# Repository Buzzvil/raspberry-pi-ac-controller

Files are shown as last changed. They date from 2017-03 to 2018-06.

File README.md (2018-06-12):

# 들어가기에 앞서
- 본 프로젝트는 외부에 공개되어 있으므로 민감한 정보가 프로젝트에 추가되지 않도록 주의해주세요.
- 개발 환경은 OSX 기준으로 되어있습니다.

# 파이콘 2017 발표자료
- [Slideshare](https://www.slideshare.net/JueunSeo1/a-to-z-78795675)
- PDF 원본

# 프로젝트 목표
- 사무실 내 3대의 에어컨을 음성 제어를 이용해 편하게 켜고 끄는게 목표입니다.
- 에어컨 2대는 같은 브랜드, 다른 한대는 다른 브랜드라서 에어컨을 켤 때 리모콘을 두 개 찾아야 하는 불편함이 있는데 이를 해결하여 에어컨 리모컨을 찾는데 들어가는 시간을 절약하여 업무 효율성을 높이자.

# TODO
- [X] [회로도 그리기](#회로도)
- [X] 빵판에 회로 만들기
- [X] 리모컨에서 나오는 ir신호 캡쳐
- [ ] 캡쳐된 ir신호 발신기 conf 파일 셋업
- [ ] irsend 이용해 에어컨 제어하기
- [ ] 서버 셋업
- [X] ngrok을 활용한 고정 public ip 할당
- [X] 도커 배포 환경 구축
- [ ] 모든 배포 환경 자동화
- [X] 만능 기판에 ir발신기 회로 구성
- [X] 아마존 에코 연동
- [ ] 슬랙으로 에어컨 켜고/끄기
- [X] 3일 이상 켜놔도 문제없이 동작하는지 확인

# 회로도
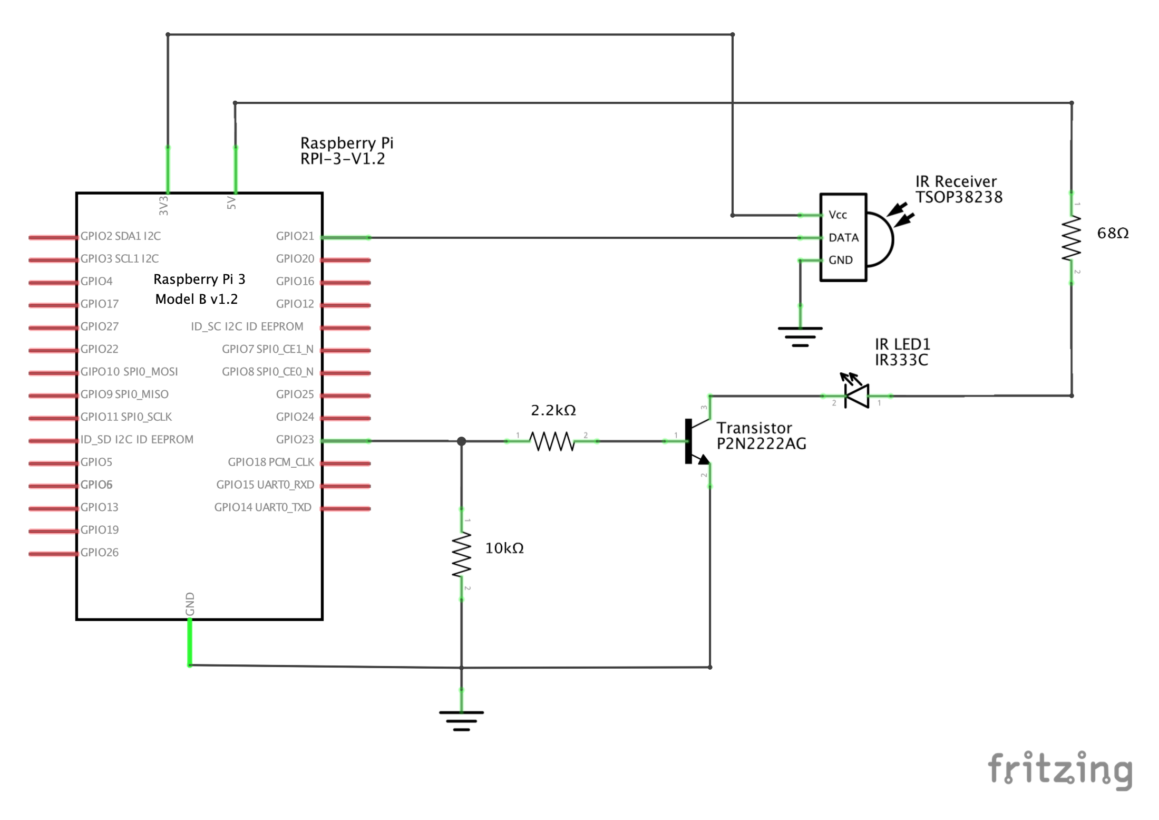
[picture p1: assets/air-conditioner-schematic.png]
schematic

Download [fritzing file(.fzz)](air-conditioner.fzz)

# 어플리케이션 구조도
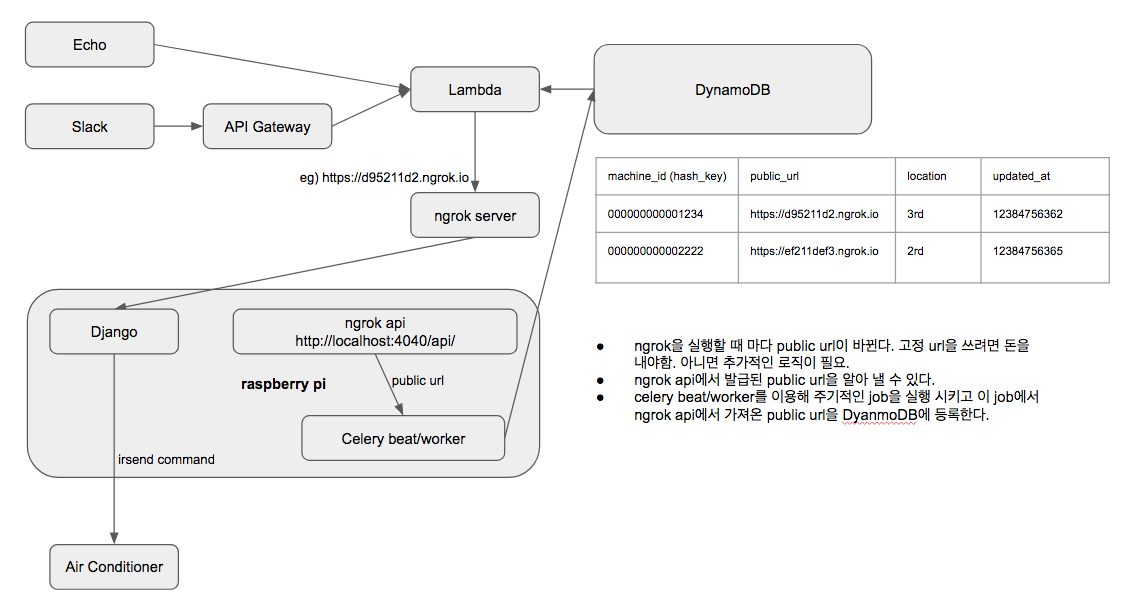
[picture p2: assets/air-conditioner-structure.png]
structure

[원본](https://docs.google.com/presentation/d/10ZRbJJHFH7znxYNwCARpbbcZcShggCh8eihLedmicmc/edit#slide=id.p)

# 회로 구성
## 준비물
- [라즈베리파이 3](http://www.eleparts.co.kr/EPXGNNFF)
- USB 아답터 2.5A 이상
- MLC SD card 16기가 -> Sandisk micro sd extreme 16GB 구매
- [빵판 or 라즈베리파이 입출력키트](http://www.eleparts.co.kr/EPXDTWPM) - 귀찮으면 입출력키트 지르자
- lirc에서 설정하는 gpio_in_pin 등의 번호는 pin 번호가 아닌 gpio 번호를 사용해야한다. 

# 개발 환경

## 라즈비안 설치 without monitor & keyboard
- [SD Card Formatter](https://www.sdcard.org/downloads/formatter_4/) 받아서 SD카드 포맷
- https://www.raspberrypi.org/downloads/raspbian/ 에서 lite version 이미지 받고 압축 풀어서 .img 파일을 실행시키면 boot volume이 마운트된다
  - http://downloads.raspberrypi.org/raspbian_lite/images/raspbian_lite-2017-04-10/2017-04-10-raspbian-jessie-lite.zip 사용 필요
  - 최신 os인 stretch에서는 samsung-ac의 irsend 동작이 됐다 안됐다 불안정하고 lg-ac에서는 간헐적으로 "irsend: timeout" 발생하는 문제가 있어 해결 될 때 까지 jessie사용 필요. 2018년 6월 12일 현재까지 문제 해결되어 있지 않음.
  - https://www.raspberrypi.org/forums/viewtopic.php?t=200865
- 기본으로 ssh가 꺼져 있기 때문에 켜기 위해서 아래처럼 파일을 생성해준다
```bash
sudo touch /Volumes/boot/ssh
```

- 아래 파일을 열어서 내용추가
```bash
sudo vi /Volumes/boot/wpa_supplicant.conf
```
```
ctrl_interface=DIR=/var/run/wpa_supplicant GROUP=netdev
update_config=1
country=US
network={
    ssid="ESSID"
    psk="Your_wifi_password"
    priority=1
}
network={
    ssid="ESSID"
    psk="Your_wifi_password"
    priority=2
    scan_ssid=1
}
```
- scan_ssid -> hidden ssid인 경우 필요
- 실제로 SD카드에 올라가고 나면 /etc/wpa_supplicant/wpa_supplicant.conf 위치에서 같은 파일 찾을 수 있다 
- [pi-baker](https://www.tweaking4all.com/software/macosx-software/macosx-apple-pi-baker/) 받아서 Restore Back으로 img파일 굽기
- network에서 라즈베리파이 찾기
```
which apr || brew install arp-scan
arp -a | grep b8:27:eb | grep -Eo '[0-9]{1,3}\.[0-9]{1,3}\.[0-9]{1,3}\.[0-9]{1,3}'

or
which nmap || brew install nmap
nmap -sn 192.168.1.0/24
```
- ssh pi@xxx.xxx.xxx.xx with password raspberry

- sudo raspi-config 실행해서 ssh 비번 바꾸기
- mkdir ~/.ssh -> vi ~/.ssh/authorized_keys 실행해서 public key 넣어놓기
- ansible로 필요한것들 설치
```bash
cd deploy/rpi/ansible
ansible-playbook -i pi@192.168.0.113, setup_rpi.yml
```

## Docker
- https://www.docker.com/docker-mac

## sshfs 설정
- https://www.raspberrypi.org/documentation/remote-access/ssh/sshfs.md
- 맥에서 아래 명령 수행
```
brew install Caskroom/cask/osxfuse
brew install sshfs
mkdir pi
sshfs pi@192.168.0.109: pi
```

## LIRC 이용한 적외선 신호 발신기 등록 및 신호 송신

- LIRC(Linux Infrared Remote Control) : http://www.lirc.org/html/configuration-guide.html
- 라이브러리 및 환경 설정은 다 되어있다는 가정

1. IR receiver 와 lirc 간 연계 테스트 : 셋업해 둔 IR receiver 가 lirc 로 정상적으로 IR 신호를 전달하고 있는지 확인용.

```bash
sudo /etc/init.d/lirc stop // lirc deamon 중단
mode2 -d /dev/lirc0
```

실행 후 IR 송신기의 버튼을 눌렀을 때 터미널에 `space, pulse` 등의 문자가 출력되면 정상.

2. irrecord 이용해 송신기의 환경 설정 파일 생성
- lirc 가 중지된 상태여야 함
```bash
irrecord -d /dev/lirc0 --disable-namespace -f ~/lircd.conf
```
- `--disable-namespace` : 각 키에 할당할 수 있는 lable의 리스트가 원래 정해져 있는데, 사용할 label을 직접 정의해서 사용하려고 하는 경우 추가. 원래 정의할 수 있는 label 리스트는 `irrecord --list-namespace` 로 조회 가능.

3. samsung ac 인식
- irrecord 대신에 mode2 사용해야함
```
sudo mode2 -m -d /dev/lirc0 > ~/lirc.conf
```

# 이슈
- docker for mac clock skew
```
https://github.com/docker/for-mac/issues/17
맥이 잠자기 모드 갔다오면 clock skew가 생기는 문제가 있다
이때 boto library 사용시 
An error occurred (InvalidSignatureException) on request () on table () when calling the DescribeTable operation: Signature expired: 20170503T140209Z is now earlier than 20170503T144558Z (20170503T150058Z - 15 min.)
와 같이 에러가 발생한다
docker image에 ntp 설치해서 해결
```

# 고민거리
- 환경 설정을 도커로 하면 이점이 있을까?
- 에어컨 3대를 제어하기 위해서는 ir 발신기가 장착된 라즈베리파이 3대가 필요한데 블루투스 -> 적외선 신호로 변환해주는 모듈이 어딘가 존재하지는 않을까? ir발신기의 유효 거리가 길지 않고 각도가 좁은게 문제인데 이를 해결할 방법이 있으면 좋겠다. 원가절감을 어떻게 할 것인가.
- 만능기판 레이아웃도 그려야하나?

# Research & Study
## 회로도 작성 툴 선택
 - https://trends.google.com/trends/explore?q=fritzing,Eagle%20Cad,circuits.io
 - https://ptarmiganlabs.com/blog/2013/08/27/fritzing-vs-circuits-io-vs-eagle-comparing-schematics-editors/
 - fritzing vs Eagle Cad vs circuits.io ?
 - fritzing이 무난해 보인다
 
## 납땜 환경 구축
### 준비물
- FX-888D(70W)
- 칼팁 T18-K
- 테프론 와이어 AWG30 (AWG숫자가 작을수록 굵고 저항이 작음)
- KESTER Solder 1mm
- Burnley 솔더링 페이스트
- Hakko Solder Wick 1.9mm
- PCB지지대 (긴거 수, 짧은거 암)
- VETUS [SS-SA] 스테인레스 정밀 무광핀셋
- 소켓 점퍼케이블 DC-40P 20CM (F/F)
- 핀 헤더 한줄짜리 PH01(2.54)-SS40P-11.5MM -> 두줄짜리 자르기 힘듦
- [만능기판](http://www.eleparts.co.kr/EPXDFA87) - 페놀보다는 좀 더 좋은 에폭시 재질을 구매
 
## 회로
- 부품 주문 시 패키지 타입을 잘 체크하자. 예를들어 빵판에 회로 구현하는데 칩 저항 사면 못 붙인다. 고정저항(LEAD)을 주문해야함.
- 모든 부품은 인터넷에 찾아보면 데이터시트가 있으니 데이터시트 보는데 익숙해지자.

## 저항 구매 팁
- 탄소피막저항 lead 타입 1/4W 5% 짜리로 구입. 1/2W로 사면 크기가 좀 크다.

## IR emitter 선택
- 파장 940nm 짜리 필요
- 발신 각도 넓은것으로 구매하자
- [IR333C] - 40도 짜리 그냥 싸고 적당한 제품
- 마운팅 타입 후보 http://www.vishay.com/ir-emitting-diodes/d
- [VSMB10940X01](http://www.vishay.com/ir-emitting-diodes/list/product-84216/)
- [VSMY1940X01](http://www.vishay.com/ir-emitting-diodes/list/product-84214/)
- [VSMY3940X01](http://www.vishay.com/ir-emitting-diodes/list/product-84220/)
- [디지키](https://www.digikey.com/products/en/optoelectronics/infrared-uv-visible-emitters/94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)

## 라즈베리파이 운영체제 선택
- Android things, Ubuntu Mate, Raspbian 등이 있는 것 같음
- GUI쪽에 특별히 신경쓸게 아니라면 뭘 쓰던 상관 없는 것 같고 공식으로 지원하는 Raspbian이 아무래도 호환성이 좋을 듯 하고 레퍼런스 찾기도 쉬울 것 같아 좋지 않을까 생각함
- Raspbian도 데비안 기반이라 apt-get 명령도 쓸 수 있는등 우분투에 익숙하다면 쉽게 쓸 수 있을 것 같다

## 부품구매 사이트 추천

### 국내
- http://www.eleparts.co.kr/
- http://www.devicemart.co.kr/
- http://www.icbanq.com/

### 해외
- http://www.digikey.com/ -> 어디서 살 지 모르겠으면 여기서 사라
- https://www.ti.com/ -> 학교 메일 있으면 샘플을 공짜로 받을 수 있었던 것으로 기억

# 레퍼런스
## IR 제어
- [Setting up LIRC on the RaspberryPi](http://alexba.in/blog/2013/01/06/setting-up-lirc-on-the-raspberrypi/)
- [라즈베리파이로 에어컨 제어하기](http://pickykang.tistory.com/37)
- [버섯돌이의 허큘렉스 다루기 - IR 입문(2.LIRC 설정및 테스트)](http://www.icbanq.com/pbloger/board_View.aspx?number=657)
- [lirc 0.9.4c 기준 설정파일](https://github.com/mtraver/rpi-ir-remote)
  - 기존 lirc 설정 문서들은 0.9.0 기준이라 안맞다. 이 링크를 확인하자.

## 납땜 준비
- [납땜 기초 알아보기](https://kocoafab.cc/tutorial/view/512)
- [누구나 할수 있는 납땜의 기초 - 필요 장비의 소개](http://zecca.tistory.com/167)

## SD카드 구매
- [라즈베리파이3 어떤 micro SD 메모리를 구입해야 하는가?](http://m.blog.naver.com/alkydes/220699946626)
- [라즈베리파이 개론 - SD 카드 선택](http://nogada-lab.tistory.com/13)

## Alexa
- [Steps to Create a Smart Home Skill](https://developer.amazon.com/public/solutions/alexa/alexa-skills-kit/docs/steps-to-create-a-smart-home-skill)
- [Linking an Alexa User with a User in Your System](https://developer.amazon.com/public/solutions/alexa/alexa-skills-kit/docs/linking-an-alexa-user-with-a-user-in-your-system)
- [Smart Home Skill API Reference](https://developer.amazon.com/public/solutions/alexa/alexa-skills-kit/docs/smart-home-skill-api-reference)
- [A quick OAuth example using Alexa to connect to Facebook](http://matchboxmobile.com/blog/oauth-using-alexa/)

# Memo
- https://pinout.xyz/ -> P01 == GPIO01 == BCM 01

sudo mode2 -m -d /dev/lirc0
https://codebender.cc/library/Souliss#extras%2FSamsungMH026FB.cpp
https://stackoverflow.com/questions/11863920/samsung-ir-codes-checksum?rq=1
라즈베리파이 안에서 docker image 받자마자 전원 뽑으면 disk에 이미지가 완전히 flush되지 못하는 경우가 생겨서 이미지가 깨져 실행이 안되는 경우가 있으니 주의.

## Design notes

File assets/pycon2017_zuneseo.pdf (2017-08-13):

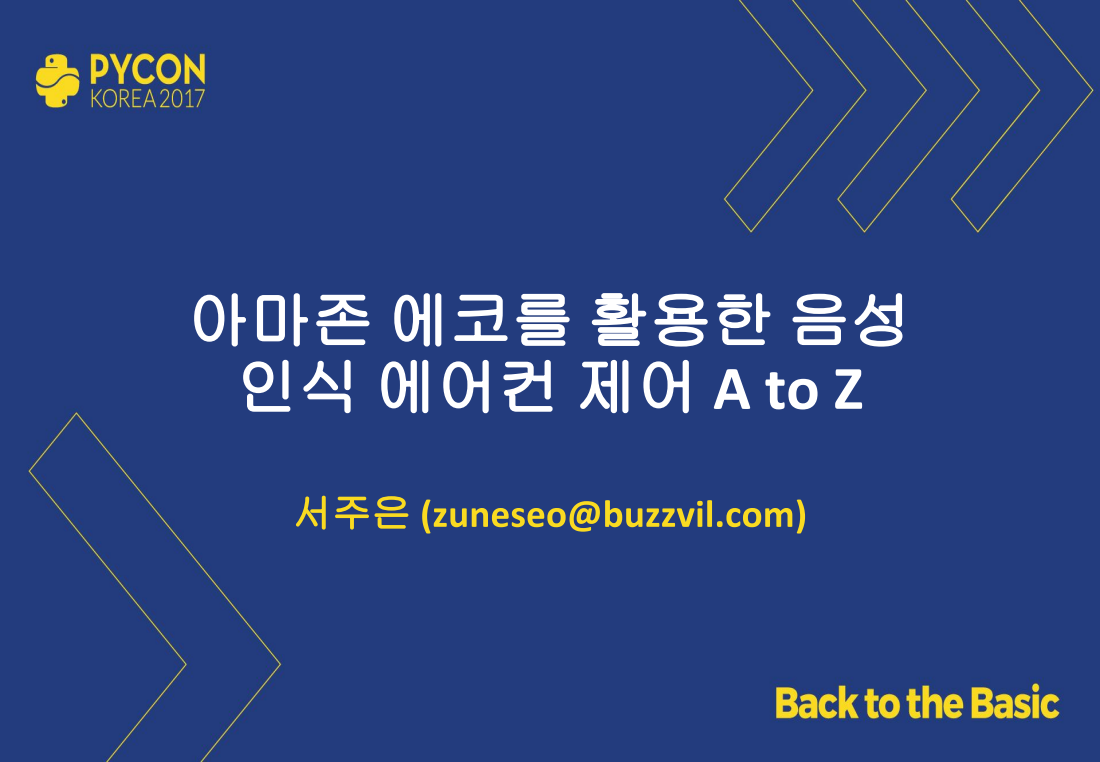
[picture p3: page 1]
서주은

아마존 에코를 활용한 음성
인식 에어컨 제어

프로젝트 목표

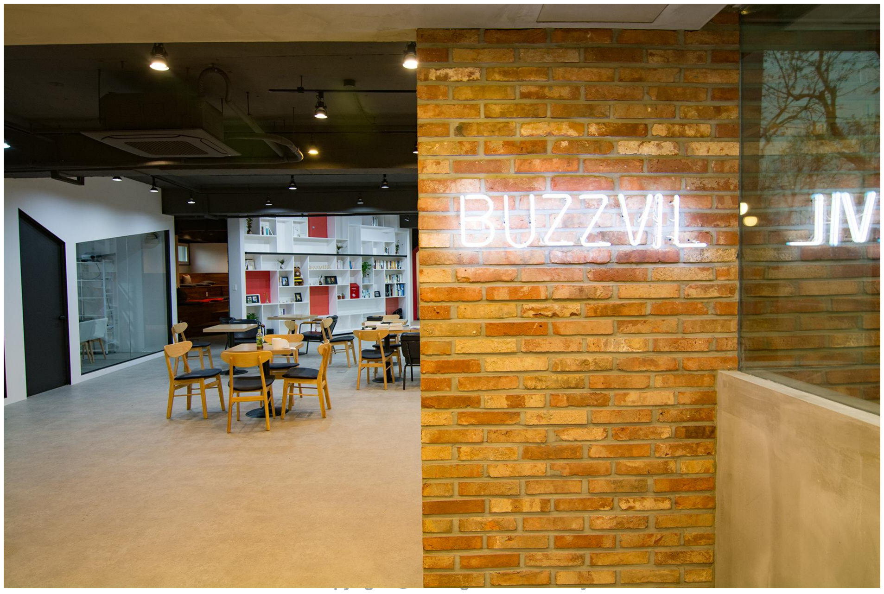
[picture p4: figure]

Copyright ⓒ All Right Reserved by Buzzvil | 2
- 사무실에 있는 에어컨을 쉽게 끄고 켤 수 있는 방법은 없을까?
- 무려 3대의 에어컨이 존재
- 심지어 모델마저 제각각이라 2개의 리모콘이 필요

프로젝트 목표

Copyright ⓒ All Right Reserved by Buzzvil | 3
- 에코를 이용한 에어컨 제어
- Alexa, turn on the AC.
- Alexa, turn off the air conditioner.
- Alexa, could you please turn on the AC?

프로젝트 목표

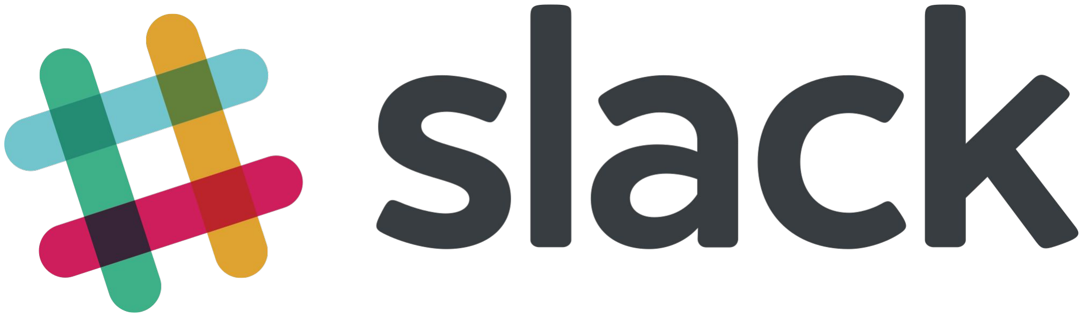
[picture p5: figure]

Copyright ⓒ All Right Reserved by Buzzvil | 4
- Slack 커맨드 만들기
- /acon - 에어컨 끄기
- /acoff - 에어컨 켜기
- /acwarm - 에어컨 약하게
- /acmedium - 에어컨 중간
- /accool - 에어컨 세게

하드웨어 만들기

Copyright ⓒ All Right Reserved by Buzzvil | 5
- 리모컨
- 적외선 통신
- 단방향 통신
- 에어컨의 상태는 리모컨에
저장되어 있다

하드웨어 만들기

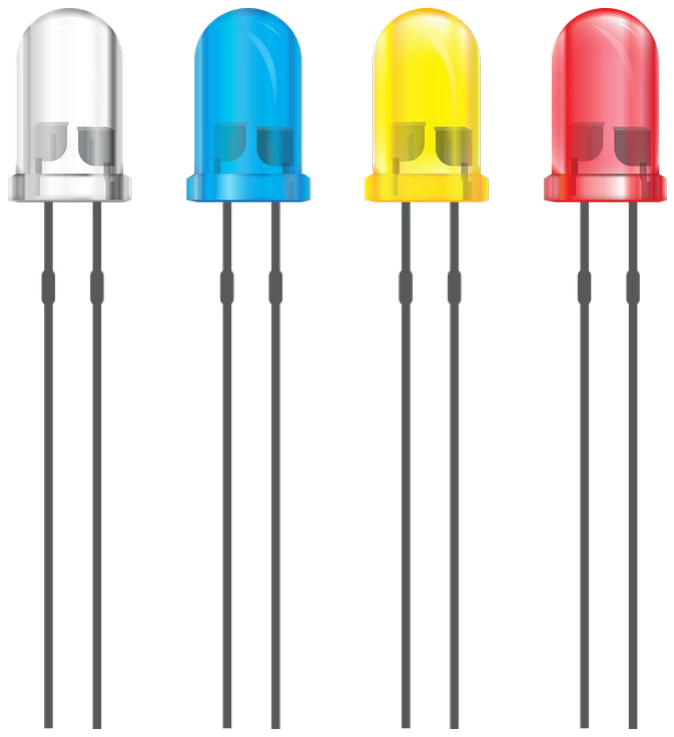
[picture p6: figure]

Copyright ⓒ All Right Reserved by Buzzvil | 6
- 적외선 발신기
- LED의 일종
- 전기에너지를 빛 에너지로
- 적외선/가시광선/자외선
- 깜빡임의 주기를 통해
데이터를 전달

하드웨어 만들기

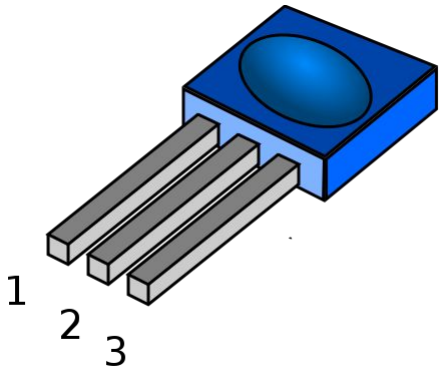
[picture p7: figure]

Copyright ⓒ All Right Reserved by Buzzvil | 7
- 리모컨 프로토콜 알아내기
- IR receiver 이용해 캡쳐

하드웨어 만들기

Copyright ⓒ All Right Reserved by Buzzvil | 8
- Echo: Amazon Echo
- RPI: Raspberry pi
- AC: Air conditioner

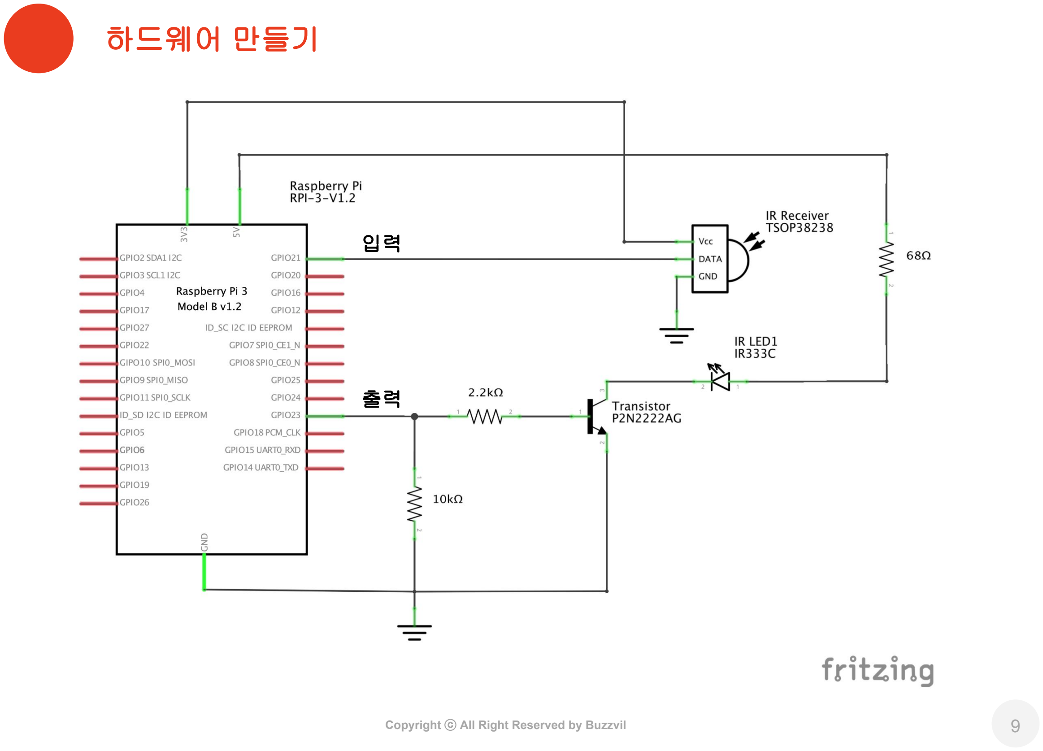
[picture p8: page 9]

하드웨어 만들기

Copyright ⓒ All Right Reserved by Buzzvil | 9

입력

출력

하드웨어 만들기

Copyright ⓒ All Right Reserved by Buzzvil | 10

LIRC

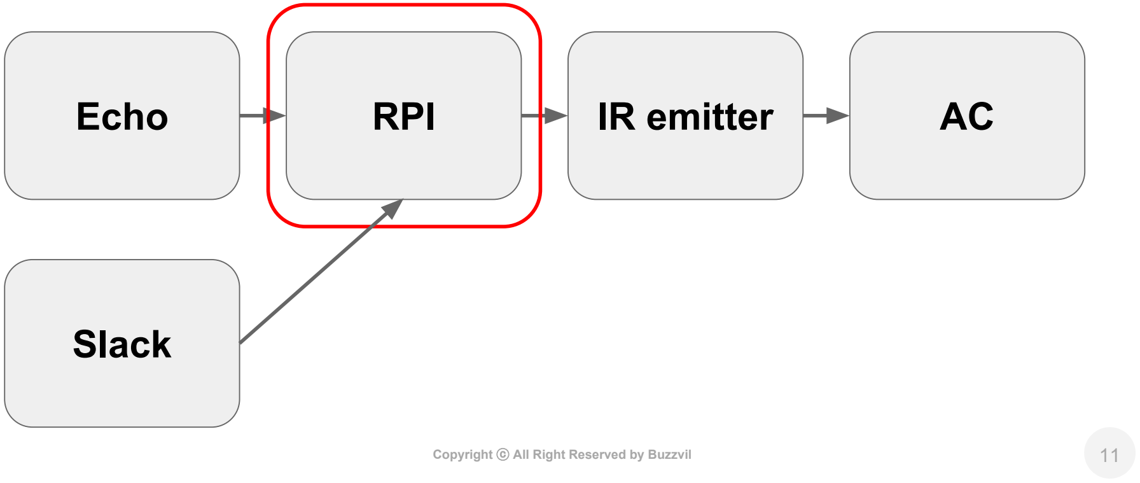
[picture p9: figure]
Echo; RPI; IR emitter; Slack

Copyright ⓒ All Right Reserved by Buzzvil | 11

LIRC

Copyright ⓒ All Right Reserved by Buzzvil | 12
- LIRC (Linux Infrared Remote Control)
- 적외선 신호를 보내고 받을 수 있게 해주는 패키지
- sudo apt-get install lirc
- LIRC commands
■ mode2
■ irsend
■ irrecord
- LIRCD
■ Client application이 Unix domain socket을 통해 쉽게 적외선 신호 송수신을 해주는 데몬

LIRC

Copyright ⓒ All Right Reserved by Buzzvil | 13
- irrecord
- irrecord -d /dev/lirc0 lircd.conf

LIRC

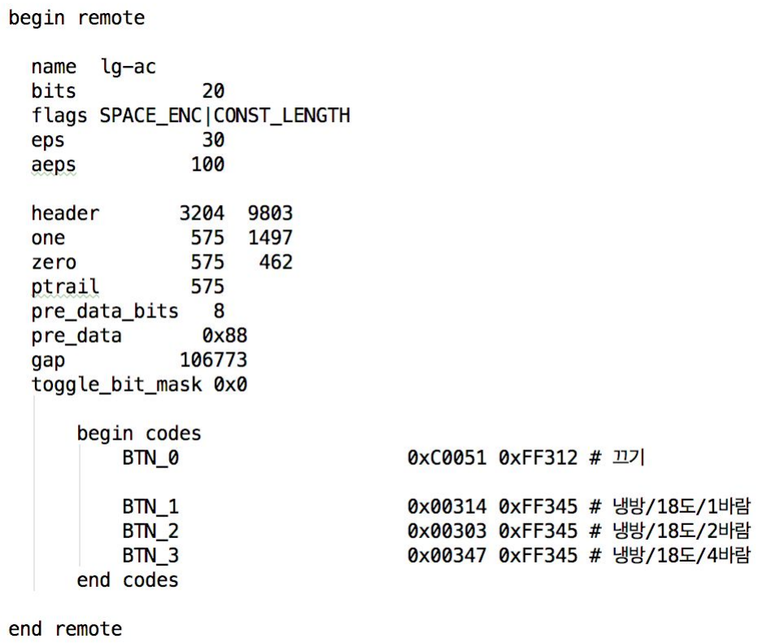
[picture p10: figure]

Copyright ⓒ All Right Reserved by Buzzvil | 14
- lircd.conf

LIRC

Copyright ⓒ All Right Reserved by Buzzvil | 15
- LG 에어컨 프로토콜 분석
- 온도/바람 세기는 왼쪽
값에서 설정
- 오른쪽 값은 누른
버튼에 대한 값
- 단방향 통신의
제약으로 인해
에어컨의 모든
상태값을 항상
전송해야함
- 전원 on 커맨드 = 전원
on + 온도 + 바람세기

LIRC

Copyright ⓒ All Right Reserved by Buzzvil | 16
- 삼성 에어컨 프로토콜 분석
- irrecord로 분석이 안됨
- 체크섬 로직이 있다고 함
- mode2 사용
- 저수준의 IR waveform capture command
- 결과를 lircd.conf 포맷으로 출력해주는 -m 옵션 사용
- sudo mode2 -m -d /dev/lirc0 > lirc.conf

LIRC

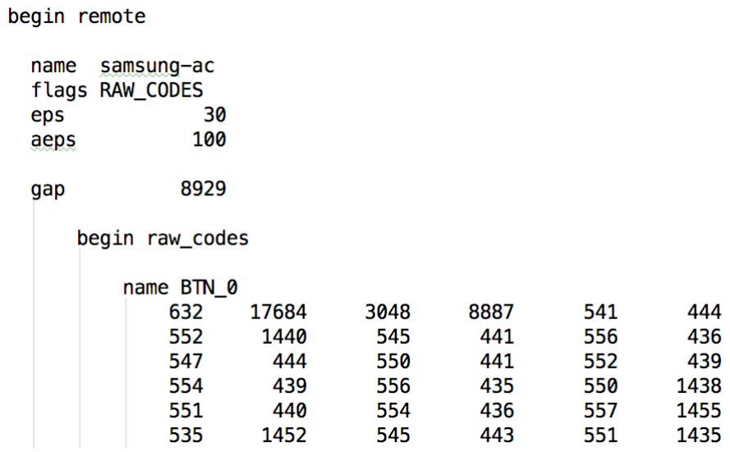
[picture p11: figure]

Copyright ⓒ All Right Reserved by Buzzvil | 17
- 삼성.. A~C(..8) 노가다!

LIRC

Copyright ⓒ All Right Reserved by Buzzvil | 18
- irsend
- irsend SEND_ONCE lg-ac BTN_1
■ lg-ac 디바이스에 BTN_1에 해당하는 신호를 한 번 보내라
- irsend SEND_ONCE samsung-ac BTN_2

LIRC

Copyright ⓒ All Right Reserved by Buzzvil | 19

애플리케이션

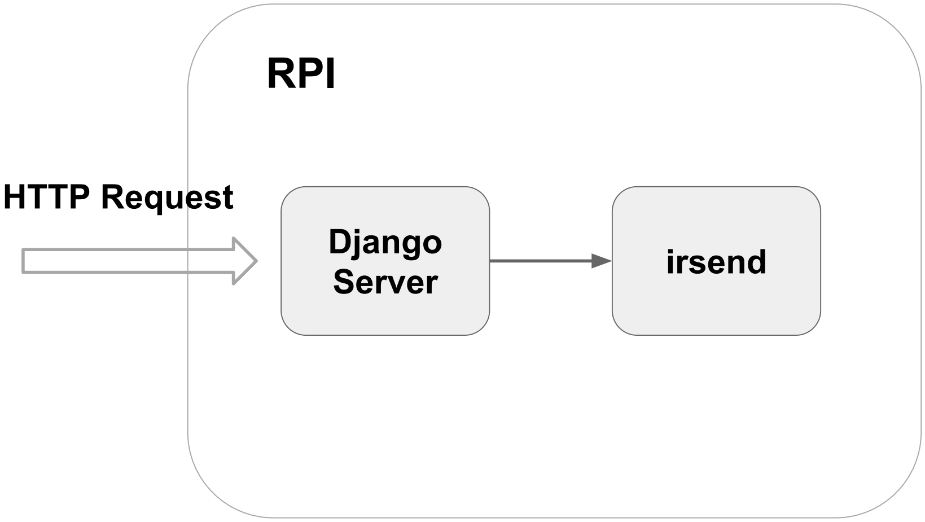
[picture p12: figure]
Django; Server; irsend; RPI; HTTP Request

Copyright ⓒ All Right Reserved by Buzzvil | 20

애플리케이션

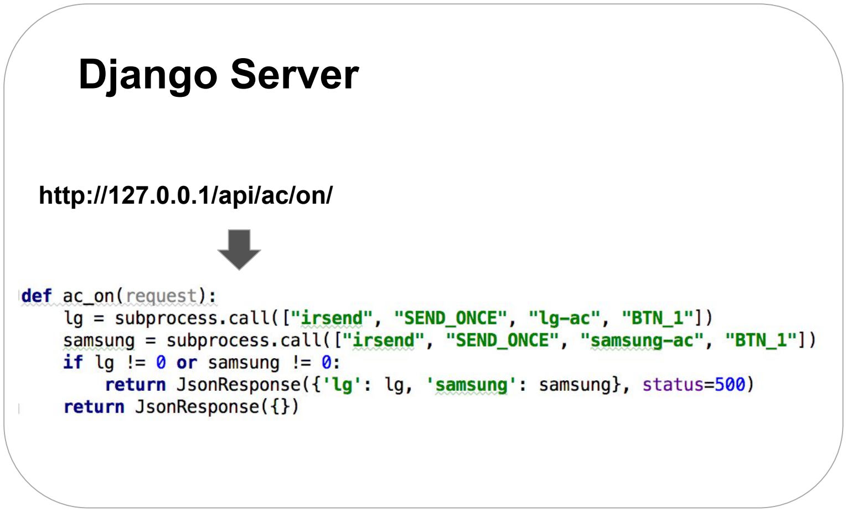
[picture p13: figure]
Django Server; http://127.0.0.1/api/ac/on/

Copyright ⓒ All Right Reserved by Buzzvil | 21

에코

Copyright ⓒ All Right Reserved by Buzzvil | 22

에코

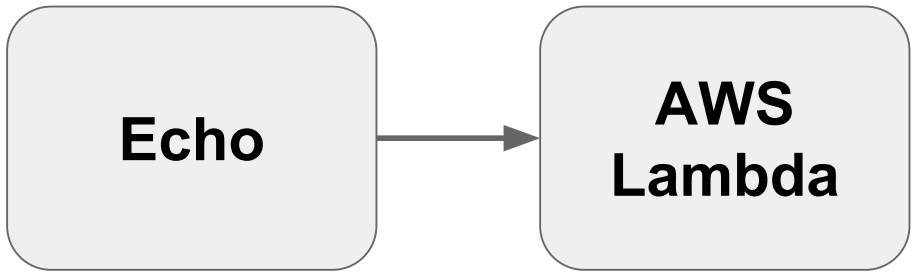
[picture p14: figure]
Echo; AWS; Lambda

Copyright ⓒ All Right Reserved by Buzzvil | 23
- 에코가 요청한 명령 핸들러 구현
- AWS Lambda라는 serverless computing service와 연동
- 다양한 연동방식
- Custom Skills
- Smart Home Skills
- Flash Briefing Skills
- Video Skills

에코

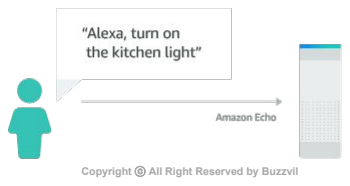
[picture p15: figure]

Copyright ⓒ All Right Reserved by Buzzvil | 24
- Smart Home Skill API
- 클라우드 연동된 스마트 홈 디바이스 제어
- 일반적으로 사용하는 명령들이 잘 정의되어 있음 ■ TurnOnRequest
■ TurnOffRequest
■ SetTargetTemperatureRequest
- Account Linking을 필수로 요구한다

에코

Copyright ⓒ All Right Reserved by Buzzvil | 25
- Account Linking
- OAuth 서버가 필요
- 사용자가 에코를 구입하고 셋업하는 시점에 Alexa Service가 Access token을 받아옴
- 팁: OAuth 서버를 직접 만드는 대신 페이스북 OAuth

Device discovery

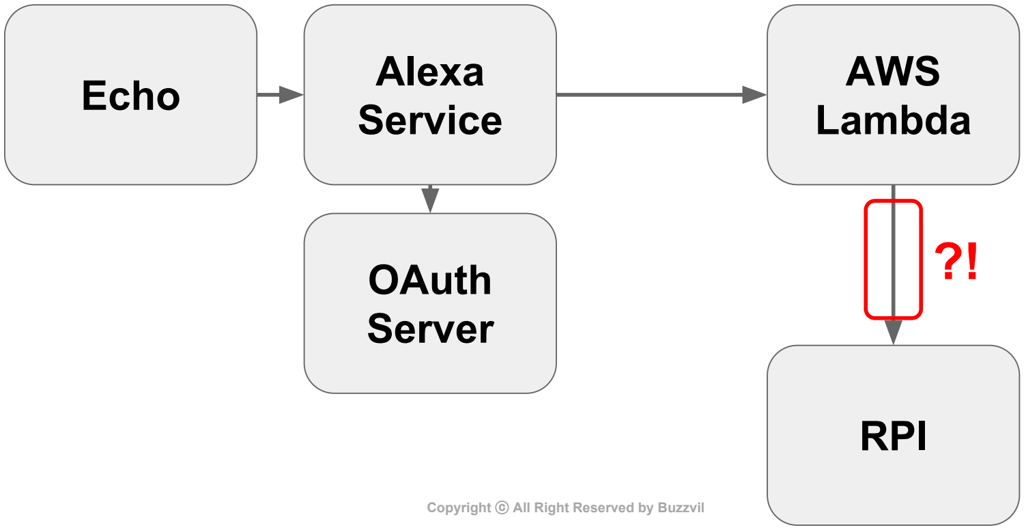
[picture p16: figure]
Echo; AWS; Lambda; Alexa Service; OAuth Server; RPI

Copyright ⓒ All Right Reserved by Buzzvil | 26
- Device discovery
- 디바이스는 공유기 내부 네트워크에 숨어있음

Device discovery

Copyright ⓒ All Right Reserved by Buzzvil | 27
- ngrok
- Secure tunnels to localhost
- "I want to expose a local server behind a NAT or firewall to the internet."

Device discovery

Copyright ⓒ All Right Reserved by Buzzvil | 28
- ngrok
- ngrok 실행시마다 도메인이 계속 바뀜
- 유료 결제를 하면 고정 도메인 사용 가능

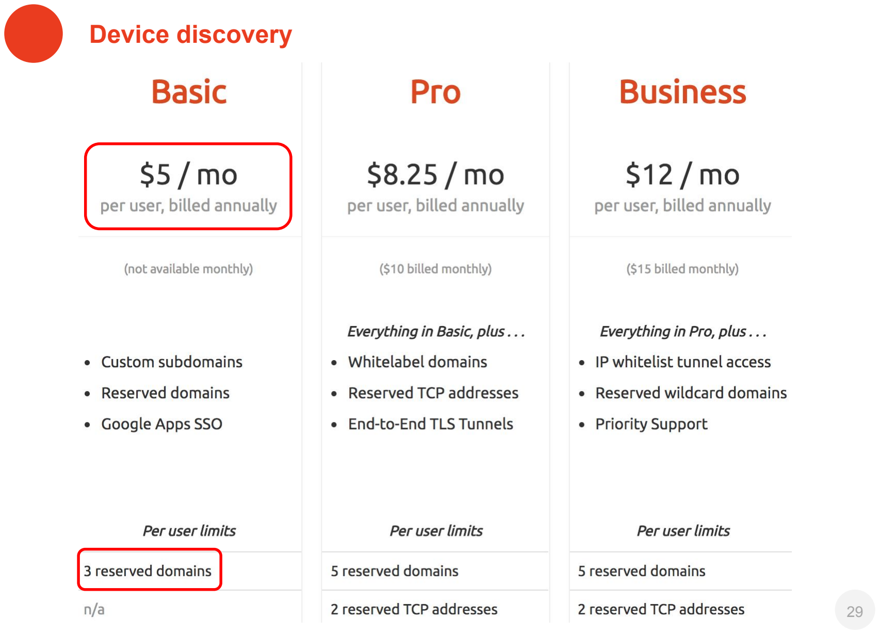
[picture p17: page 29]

Device discovery

Copyright ⓒ All Right Reserved by Buzzvil | 29

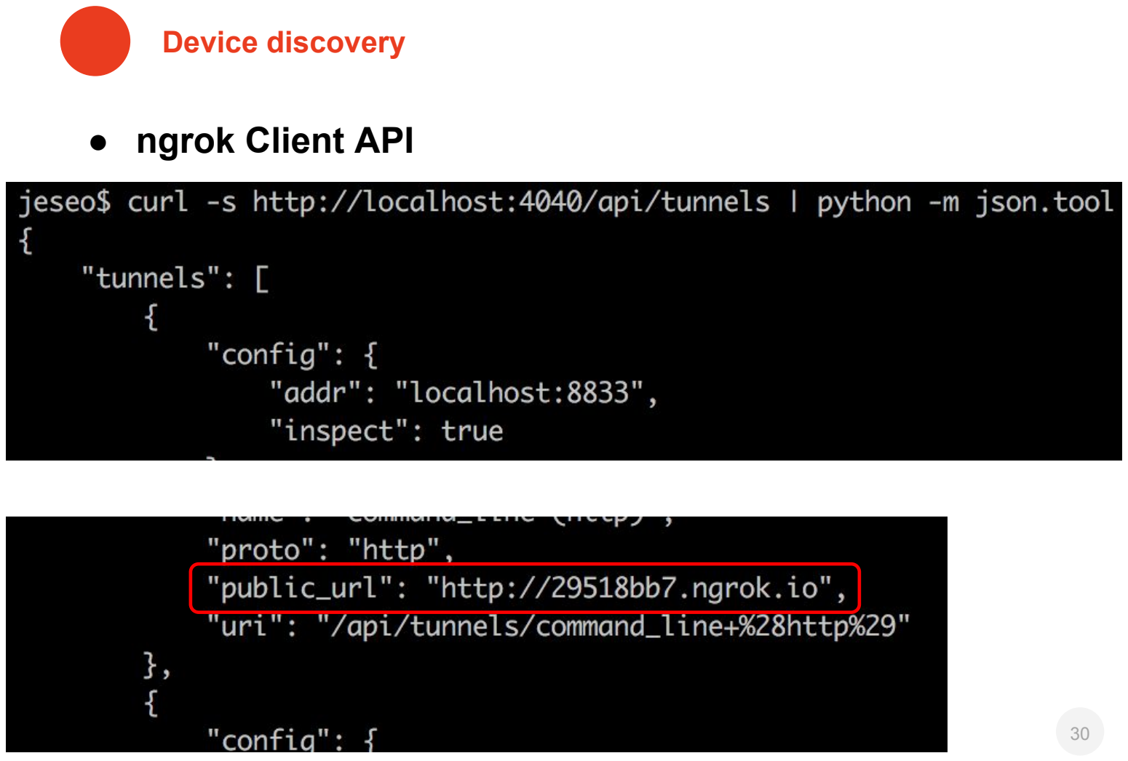
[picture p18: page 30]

Device discovery

Copyright ⓒ All Right Reserved by Buzzvil | 30
- ngrok Client API

Device discovery

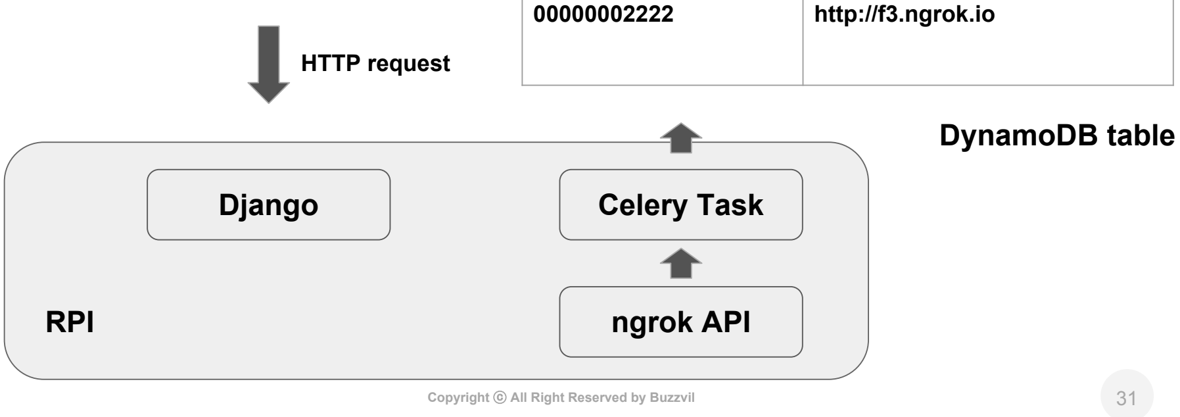
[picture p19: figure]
http://f3.ngrok.io; DynamoDB table; Celery Task; RPI; ngrok API; Django; HTTP request

Copyright ⓒ All Right Reserved by Buzzvil | 31
machine_id | public_url
00000001234 | http://d2.ngrok.io
- 주기적으로 public url을 가져와 DynamoDB table에

애플리Device discovery케이션

Copyright ⓒ All Right Reserved by Buzzvil | 32
- ngrok task
- requests/PynamoDB를 활용한 빠른 구현

Device discovery

Copyright ⓒ All Right Reserved by Buzzvil | 33
- 비용 절약
- 유료 플랜 고정 도메인 3개 가격 한달에 5 불
- DynamoDB 버지니아 기준 월 별 가격 = 0.47 불(1 write/sec) + 0.09 불(1 read/sec) = 0.56 불
- ngrok Basic 플랜에 비해 1/10의 가격으로 무제한 도메인 사용 가능
- 더 아끼고 싶으면 S3에 저장하자
- 간단한 환경에서는 공유기의 DDNS/포트 포워딩 기능 이용

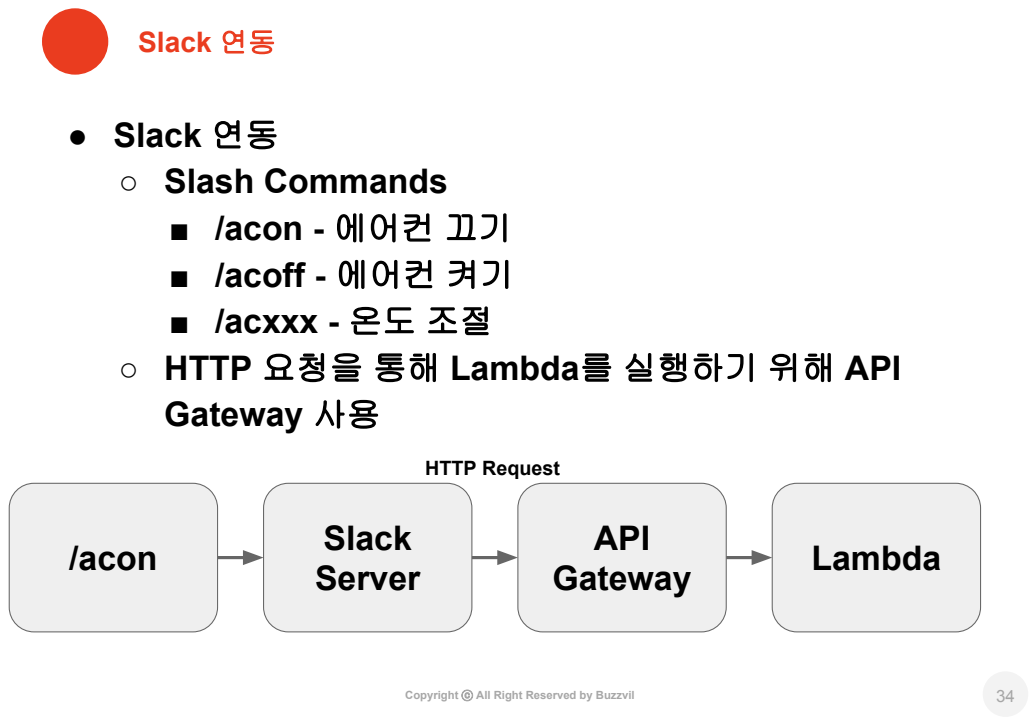
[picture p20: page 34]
Slack 연동; Copyright ⓒ All Right Reserved by Buzzvil; /acon; Slack; Server; API; Gateway; Lambda; HTTP Request

● Slack 연동
○ Slash Commands
■ /acon - 에어컨 끄기
■ /acoff - 에어컨 켜기
■ /acxxx - 온도 조절
○ HTTP 요청을 통해 Lambda를 실행하기 위해 API
Gateway 사용

Slack 연동

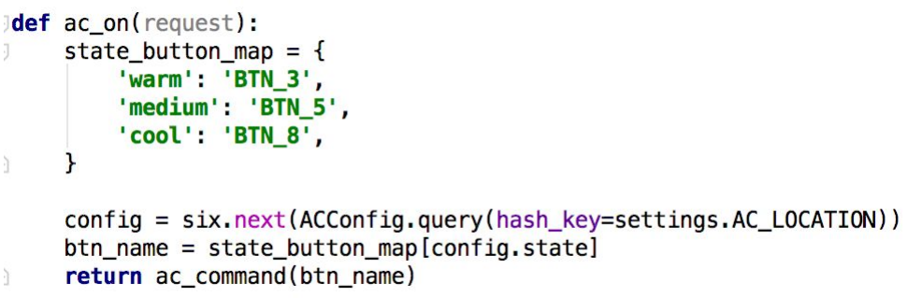
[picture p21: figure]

Copyright ⓒ All Right Reserved by Buzzvil | 35
- Temperature state aware command
- 에어컨 ON명령에는 온도값도 항상 포함이 되어있어야 한다
- /acon를 /acwarm, /acmedium, /accool 로 변환이 필요
- /acwarm, /acmedium, /accool 중 마지막에 호출된 커맨드를 저장해야함
- DynamoDB에 상태값을 저장

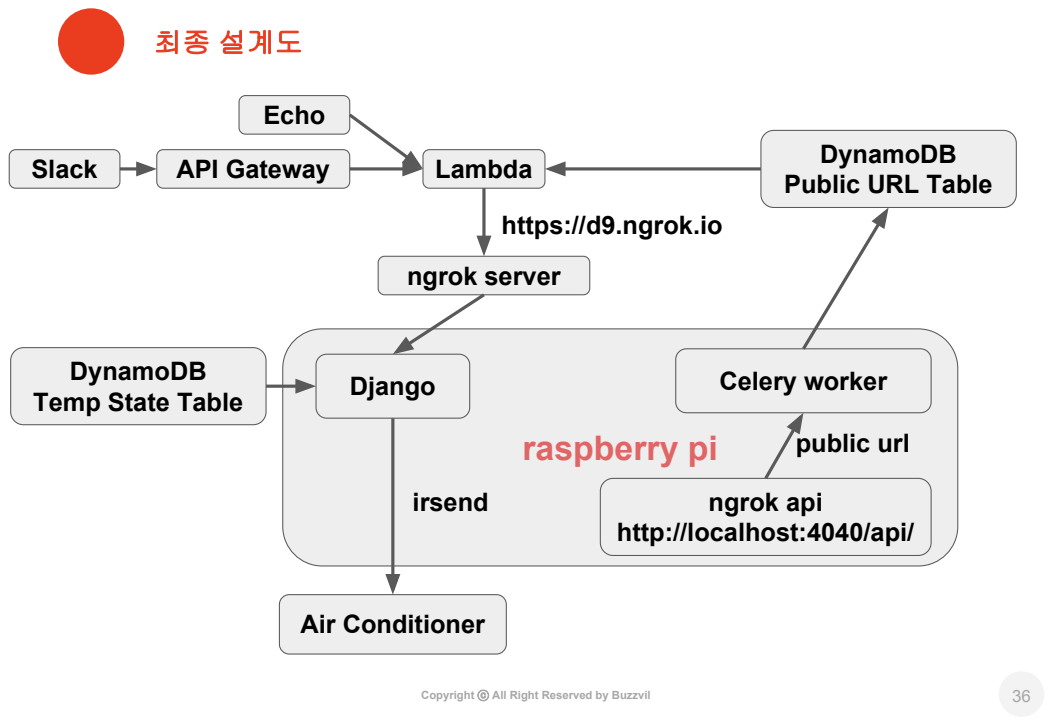
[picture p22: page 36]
최종 설계도; Copyright ⓒ All Right Reserved by Buzzvil; raspberry pi; API Gateway; Lambda; Echo; Slack; ngrok server; Air Conditioner; Django; Celery worker; ngrok api; public url; irsend

DynamoDB
Public URL Table

https://d9.ngrok.io

Temp State Table

http://localhost:4040/api/

배포 자동화

Copyright ⓒ All Right Reserved by Buzzvil | 37
- AC controller application을 설치하기 위한 단계
- IR 핀 설정
- ngrok 설치
- pip 패키지 설치 및 django project 소스코드 복사
- supervisord를 이용해 ngrok, django web server, celery worker daemonize

배포 자동화

Copyright ⓒ All Right Reserved by Buzzvil | 38
- 도커
- 쉽게 말하면 윈도우의 포터블 앱과 비슷
- 컨테이너 안에 필요한 애플리케이션을 설치하고 이미지를 만들어 라즈베리파이에서는 단순히
이미지를 받아 실행

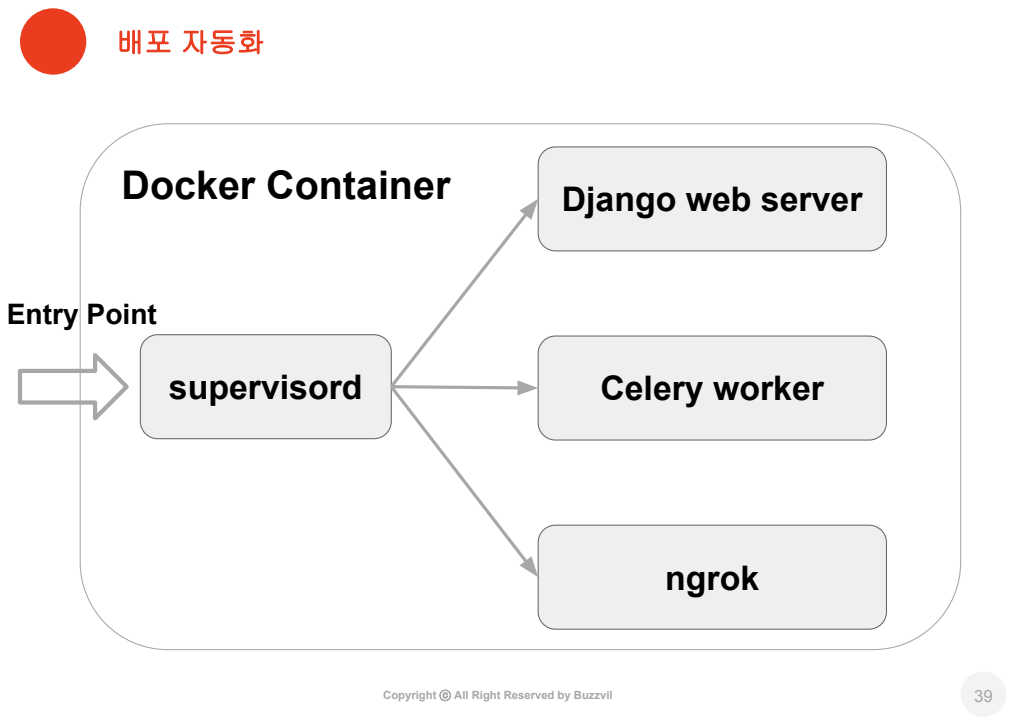
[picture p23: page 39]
배포 자동화; Copyright ⓒ All Right Reserved by Buzzvil; supervisord; Docker Container; Django web server; Celery worker; ngrok; Entry Point

배포 자동화

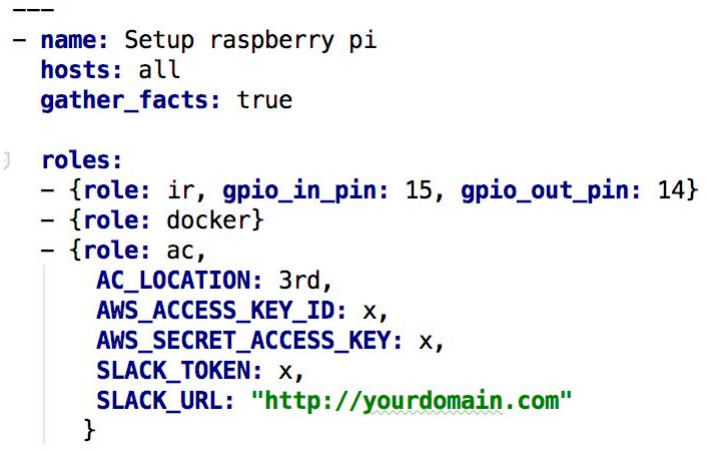
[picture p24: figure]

Copyright ⓒ All Right Reserved by Buzzvil | 40
- Ansible
- 서버 셋업 자동화 툴
- Puppet, Chef 등과 비슷하나 Agent가 필요없고 SSH 프로토콜 사용

배포 자동화

Copyright ⓒ All Right Reserved by Buzzvil | 41
- 업그레이드된 AC controller setup하기
- ansible 명령으로 application 설치
■ ansible-playbook -i hosts setup_rpi.yml
- 완성!

Copyright ⓒ All Right Reserved by Buzzvil | 42

# One more thing

One more thing

Copyright ⓒ All Right Reserved by Buzzvil | 43
- 조도 센서를 이용한 자동 어에컨 끄기

❏ 조도 센서를 폴링하여
조명이 on -> off
상태로 변경이 됐는지
체크
❏ 마지막 조명 on/off
상태값을 저장해야함
❏ 상태값은 sqlite3 db에
저장하고 Django
ORM을 통해 접근

Summary

Copyright ⓒ All Right Reserved by Buzzvil | 44
- 재료비
- 라즈베리파이3 + 공식케이스 + 방열판 = 53,350원
- SD카드 = 4,410원
- 트랜지스터 = 700원
- 적외선 LED = 400원
- 저항 = 100원
- 만능기판 = 1,300원
- 만능기판 다리 = 100원
- 점퍼 케이블 = 300원
- 총 = 60,660원
- 라즈베리파이 zero W 가 나왔습니다
- 해외 판매가 10불

Summary

Copyright ⓒ All Right Reserved by Buzzvil | 45
- 납땜을 위한 준비물 비용
- 라즈베리파이 입출력 키트 = 14,600
- 테프론 와이어 AWG30 = 5,380원
- Kester 유연납 1.0mm /50g = 4,400원
- 멀티미터 FLUKE-101 = 43,500원
- HAKKO FX-888D 디지털인두기 = 143,550원
- 교체용인두팁 T18-K = 11,880원
- 니퍼 = 집에 있는거
- 총 = 223,310원
- 에코
- 에코닷 = 55,000원

?!

Summary

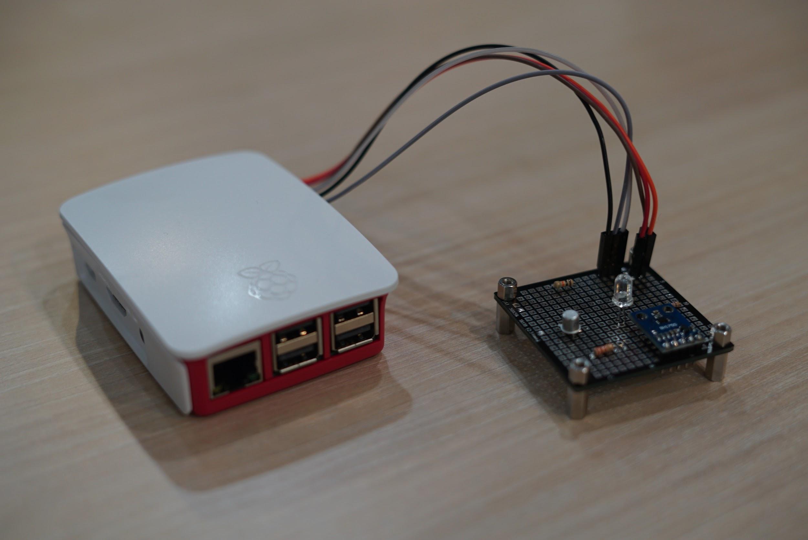
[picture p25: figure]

Copyright ⓒ All Right Reserved by Buzzvil | 46

Summary

Copyright ⓒ All Right Reserved by Buzzvil | 47

Summary

Copyright ⓒ All Right Reserved by Buzzvil | 48
- 마무리하며
- Python/Django/Celery를 활용해 필요한 애플리케이션 로직을 빠르게 개발
■ HTTP 서버 구축
■ ngrok 무료 사용
■ 에어컨 온도 설정상태 보관
■ 조도센서 상태 변경 캐치
- Django/Celery 조합을 활용해 하나의 프로젝트로 서버부터 주기적인 태스크까지 다양한 일을 수행
- Python을 활용해 빠르게 프로토타이핑을 하고 시간이 많이 걸리는 다른 부분에 집중할 수 있었음

Thanks to

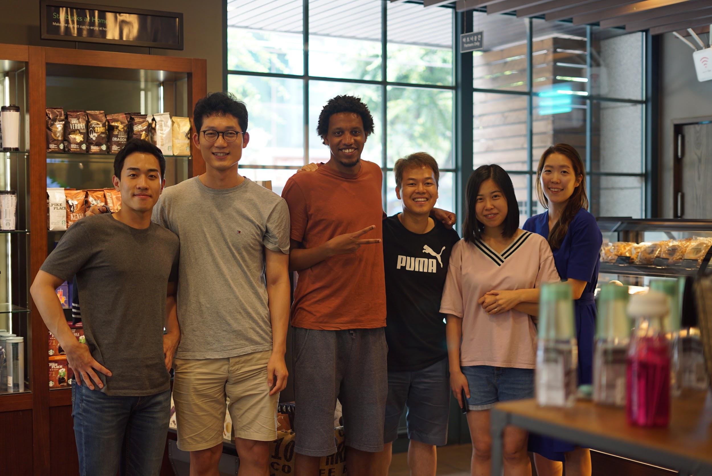
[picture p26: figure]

Copyright ⓒ All Right Reserved by Buzzvil | 49

Copyright ⓒ All Right Reserved by Buzzvil | 50

# 감사합니다

Q&A

The project is open-sourced https://github.com/Buzzvil/hardware-lab

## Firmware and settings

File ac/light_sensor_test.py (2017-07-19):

#!/usr/bin/python
# --------------------------------------
#    ___  ___  _ ____
#   / _ \/ _ \(_) __/__  __ __
#  / , _/ ___/ /\ \/ _ \/ // /
# /_/|_/_/  /_/___/ .__/\_, /
#                /_/   /___/
#
#           bh1750.py
#  Read data from a digital light sensor.
#
# Author : Matt Hawkins
# Date   : 15/04/2015
#
# http://www.raspberrypi-spy.co.uk/
#
# --------------------------------------
import smbus
import time

# Define some constants from the datasheet

DEVICE = 0x23  # Default device I2C address

POWER_DOWN = 0x00  # No active state
POWER_ON = 0x01  # Power on
RESET = 0x07  # Reset data register value

# Start measurement at 4lx resolution. Time typically 16ms.
CONTINUOUS_LOW_RES_MODE = 0x13
# Start measurement at 1lx resolution. Time typically 120ms
CONTINUOUS_HIGH_RES_MODE_1 = 0x10
# Start measurement at 0.5lx resolution. Time typically 120ms
CONTINUOUS_HIGH_RES_MODE_2 = 0x11
# Start measurement at 1lx resolution. Time typically 120ms
# Device is automatically set to Power Down after measurement.
ONE_TIME_HIGH_RES_MODE_1 = 0x20
# Start measurement at 0.5lx resolution. Time typically 120ms
# Device is automatically set to Power Down after measurement.
ONE_TIME_HIGH_RES_MODE_2 = 0x21
# Start measurement at 1lx resolution. Time typically 120ms
# Device is automatically set to Power Down after measurement.
ONE_TIME_LOW_RES_MODE = 0x23

bus = smbus.SMBus(1)

def convertToNumber(data):
    # Simple function to convert 2 bytes of data
    # into a decimal number
    return ((data[1] + (256 * data[0])) / 1.2)


def readLight(addr=DEVICE):
    data = bus.read_i2c_block_data(addr, ONE_TIME_HIGH_RES_MODE_1)
    return convertToNumber(data)


def main():
    while True:
        print("Light Level : " + str(readLight()) + " lx")
        time.sleep(1)


if __name__ == "__main__":
    main()

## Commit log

2017-03-05 django project 추가
2017-05-01 api 추가, ngrok worker추가
2017-05-02 alexa 실패시 어떤 함수 실패했는지 알려주기, 빠진 node module 추가
2017-05-02 도커 적용
2017-05-03 rpi docker image 사용, dynamodb에 데이터 넣기 완성
2017-05-07 라즈베리파이 셋업 ansible script
2017-05-07 import error 수정
2017-05-07 구조도 첨부
    [air-conditioner.fzz]
2017-05-31 Integrate light (#13)
    light, samsung-ac, lg-ac 명령 완성
2017-05-31 api에 새로 등록한 lirc 명령 적용
2017-06-02 celerybeat에서 pid 파일 사용 안함
2017-06-05 dynamodb에 hostname도 남김
2017-06-07 Response device status code
2017-06-07 docker build 이전 버전에서 build명령 호환 안되는 문제 수정 삼성 에어컨 회전 모드 ansible build시 hostname전달 제대로 안되는 문제 수정
2017-06-14 온도 조절 커맨드 추가, 익셉션 발생시 로깅
2017-07-13 travis ci 추가
2017-07-13 ac off unit test 추가
2017-07-19 조도 센서 연동 - 불 꺼지면 에어컨 끄기 (#23)
2017-07-19 very_low mode 만들고 기존 커맨드 온도 올림
2017-07-19 환경변수 master_env.sh로 옮김, public url update 주기 5초 -> 10초, pytest test*.py로 디스커버리
2017-07-19 hostname 제대로 안들어가는 문제 수정
2017-07-19 불이 켜진 상태에서 꺼진 경우만 acoff api 호출
2017-07-19 worker process 갯수 4 -> 1개로 수정, photo sensor 연결 안된 보드에서 문제 없도록 수정, 온도 설정상태 읽어오는 부분 버그 수정
2017-08-13 파이콘 2017 발표자료 업로드
2018-06-05 에어콘 바람 약할 때 냄새나서 바람세기는 항상 세게 나오도록 변경
2018-06-05 조도센서 코드 리팩토링
2018-06-05 도커 이미지 태그 이름 latest대신 날짜 사용 도커 로그 로테이트 조도 센서 검색 실패시 예외 발생하는 버그 수정 lg BTN_12가 동작하지 않아서 임시로 BTN_11로 변경
2018-06-07 ngrok이 anonymous user에 대해 session open time limit를 걸어서 refresh하기 위해 cron을 이용해 하루에 한번 씩 ngrok 재실행
2018-06-11 lirc 0.9.4c 대응
2018-06-11 ngrok 실행시 qemu-arm-static 필요 없어져서 제거 ngrok 8시간 마다 재시작 필요햐여 cron job 변경 wpa_supplicant 설정파일에 country 입력 필요 하여 적용
2018-06-12 ansible에서 비밀번호 변경 및 hostname 변경, authorized_key 복사 처리
2018-06-12 stretch와 lirc 0.9.4c에서 문제가 있어서 jessie lirc 0.9.0으로 롤백
2018-06-12 setup_rpi.yml syntax error 수정
